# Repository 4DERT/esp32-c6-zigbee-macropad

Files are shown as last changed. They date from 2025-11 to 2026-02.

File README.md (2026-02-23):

# ESP32-C6 Zigbee Macropad

A compact, 3D-printable 6-key mechanical macropad powered by the ESP32-C6. This project functions as a stylish desk gadget that allows you to easily control your smart home devices via Zigbee. 

The custom 3D-printed enclosure features a dedicated mounting point specifically designed for the **DFRobot Beetle ESP32-C6** development board and supports standard mechanical keyboard switches (Cherry MX, Outemu, etc.).

<p align="center">
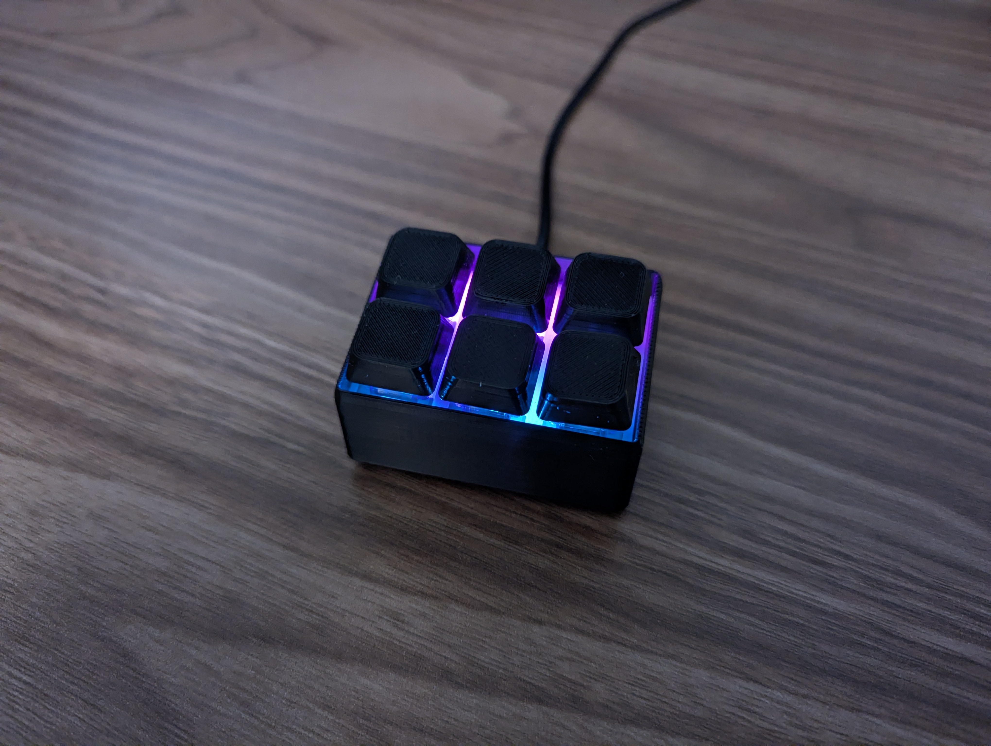
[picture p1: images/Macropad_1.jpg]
Macropad Main View
  
</p>

<p align="center">
  
</p>

## Features

* **6 Customizable Keys:** Supports up to 6 mechanical switches.
* **Multi-Action Support:** Every key independently supports **Single Press**, **Double Press**, and **Long Press** actions.
* **Zigbee Router Capability:** Can act as a Zigbee Router to extend your mesh network (configurable via `menuconfig` -> *Component config* -> *Zigbee* -> *Configure the Zigbee device type*).
* **RGB Lighting:** Support for WS2812 addressable LED strips with various animations. It also supports standard, non-addressable LEDs (like the board's built-in LED).
* **Function (FN) Layer:** A secondary layer is available for device management (accessed by holding a designated key, default is **Key 5**).
  * **Lighting Control:** Use the FN layer to change RGB effects, brightness, and colors.
  * **Configurable Activation:** You can set the FN layer to trigger via a standard *Classic Hold* (active while pressed) or via a *Long Press* (which frees up the single/double press actions of that key for additional Zigbee commands).
  * **Factory Reset:** Hold **FN (Key 5)** and press **Key 2** (the key directly above it) to factory reset the device and force it to leave the current Zigbee network.

## Gallery

<p align="center">
  <table>
    <tr>
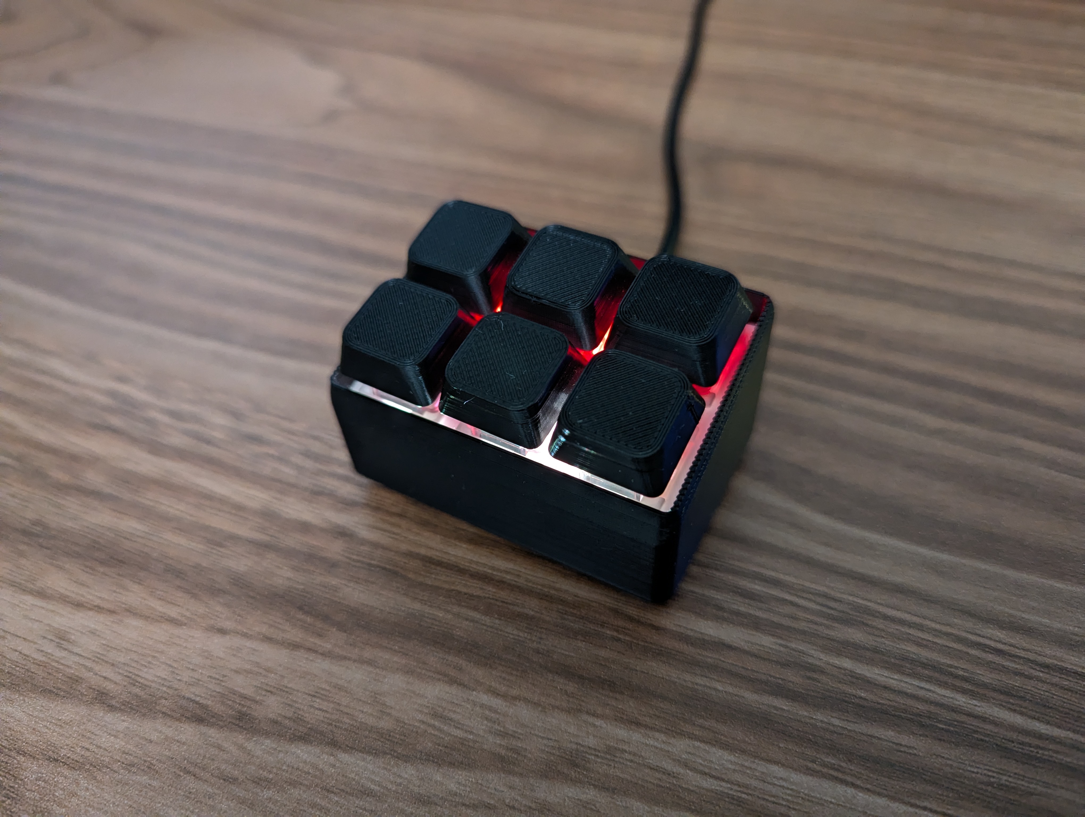
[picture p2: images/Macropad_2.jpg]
Macropad View 2
      <td></td>
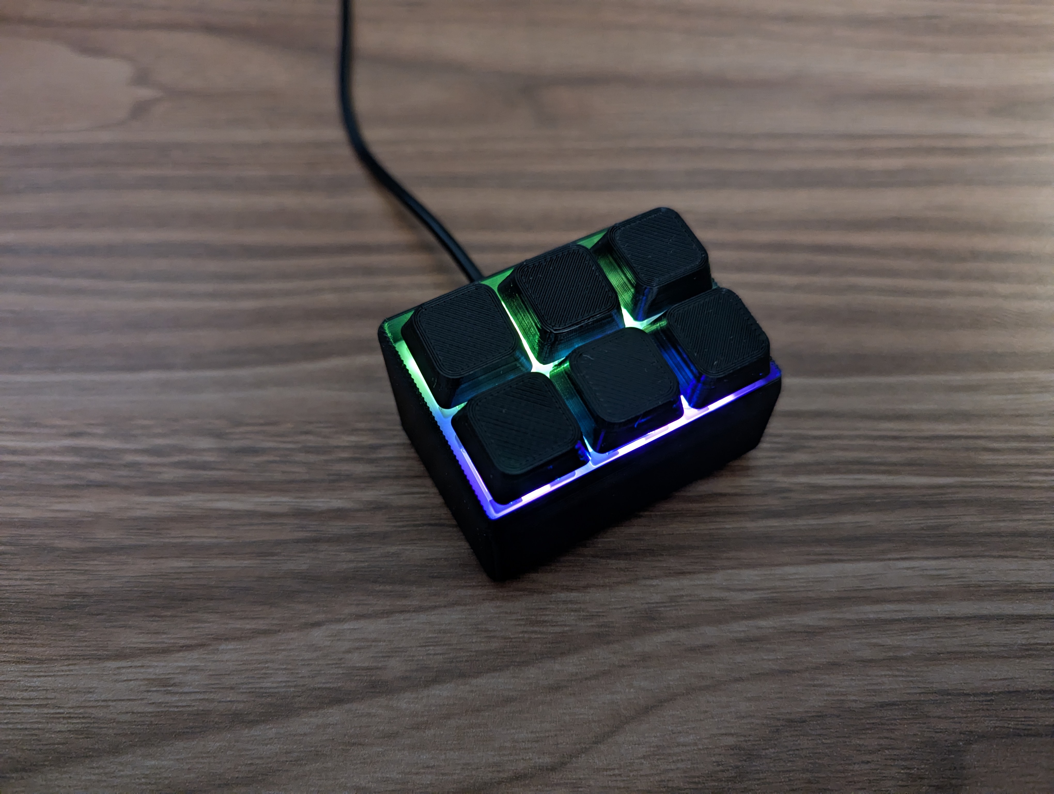
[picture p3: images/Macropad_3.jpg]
Macropad View 3
      <td></td>
    </tr>
    <tr>
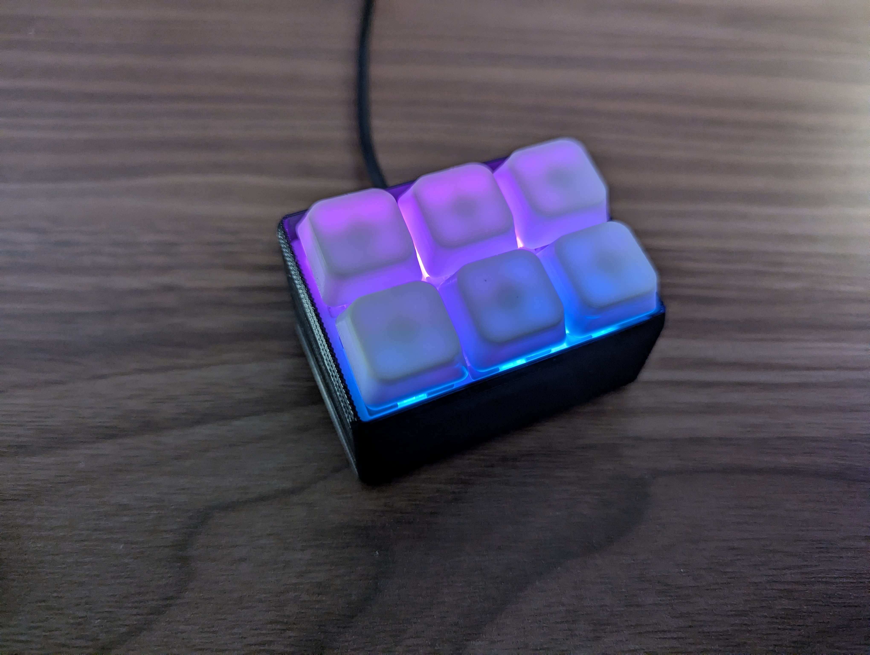
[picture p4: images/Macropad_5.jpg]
Macropad View 5
      <td></td>
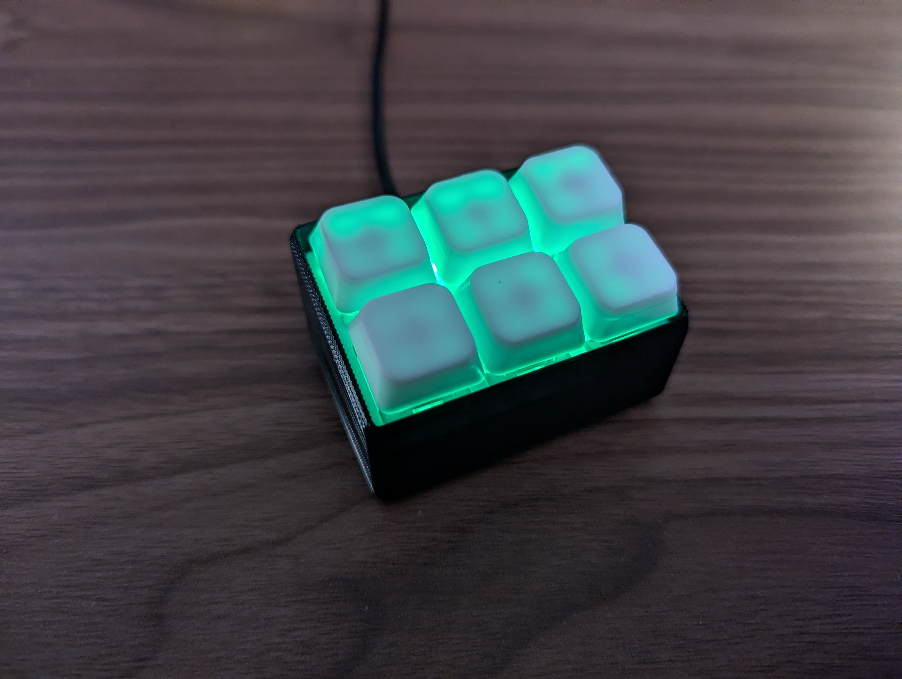
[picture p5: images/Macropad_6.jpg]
Macropad View 6
      <td></td>
    </tr>
  </table>
</p>

## 🛠️ Hardware & Components
* 1x [DFRobot Beetle ESP32-C6](https://www.dfrobot.com/product-2778.html)
* 6x Mechanical Keyboard Switches - pick your favorite color/feel - [Example Link](https://aliexpress.com/item/1005005876614581.html)
* *(Optional)* RGB Strip: 5mm WS2812B 100 LEDs/m. You only need 10 LEDs total (5 for each side) - [Example Link](https://aliexpress.com/item/1005006739134777.html)
* *(Optional)* 1x 100–470 µF Low ESR Capacitor (Highly recommended if using the WS2812 RGB strip)
* Hookup wire (silicone wire recommended for flexibility)
* 2x M2 20mm screws
* 1x M2 4mm screw (or 5mm with a washer)
* 3x M2 Knurled threaded inserts (M2\*3\*3.5)

## 3D Printing & Assembly
The `STL` folder contains all the core enclosure files (`Base`, `Plate`, etc.).

> **Note about Keycaps:** Keycap files are not included in the repository. You can use any standard keycaps that fit your chosen mechanical switches (e.g., Cherry MX compatible), or you can easily 3D print your own! If you want to print them, here is a great [DSA-like MX Keycap model on MakerWorld](https://makerworld.com/en/models/1412642-keycap-mx-dsa-like) that fits perfectly.

> **Printing Tip:** If you are using the addressable RGB strip, it is highly recommended to print the `Base` in **Black** (to prevent light bleed) and the `Plate` in **White** (to nicely diffuse the LED light).

1. Insert the knurled threaded nuts into the designated mounting posts in the base using a soldering iron.
2. Snap your mechanical switches into the printed `Plate`.
3. Solder wires to the switch pins and route them to the ESP32-C6. 

### Wiring Guide

| Button | ESP32-C6 GPIO |
| :---: | :---: |
| **0** | `GPIO 21` |
| **1** | `GPIO 22` |
| **2** | `GPIO 20` |
| **3** | `GPIO 7` |
| **4** | `GPIO 19` |
| **5** | `GPIO 6` |

Wiring Diagram

**RGB Strip (WS2812):** 
* Connect the data line to **GPIO 17**.
* Connect Power to **VIN** (5V) and Ground to **GND**. 
* *Note: It is highly recommended to solder a 100–470 µF Low ESR capacitor across VIN and GND to stabilize power for the LEDs.*

*(You can easily change the pinout configuration in `menuconfig`. The configuration above matches the pre-compiled binary available in the Releases tab).*

Once wired, carefully tuck the wiring and components into the enclosure and screw everything together.

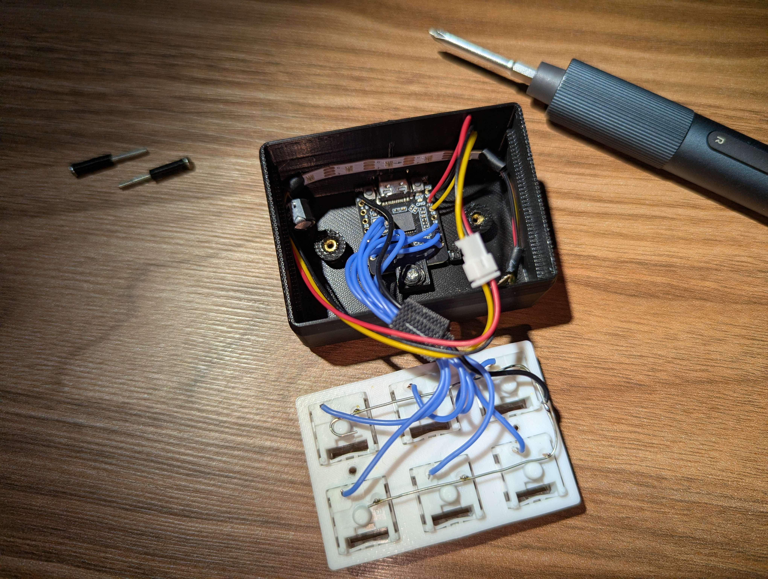
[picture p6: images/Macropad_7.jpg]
Internal Assembly


## Building & Flashing

### Quick Flash (Pre-compiled Binary)
If you don't want to set up a development environment, you can flash the pre-compiled firmware directly from your browser!

1. Download the latest firmware image (`.bin` file) from the `Releases page` of this repository.
2. Open the [ESP Web Flasher by Spacehuhn](https://esptool.spacehuhn.com/) in a Web Serial-compatible browser (e.g., Google Chrome or Microsoft Edge).
3. Connect your ESP32-C6 to your computer via USB and click **Connect** on the webpage.
4. Select the correct serial port for your device.
5. Upload the downloaded `.bin` file, set the flash address to `0x0`, and click **Program** to flash the device.

### Build from source code
1. Clone the repository and open it in **VS Code**.  
   A ready-to-use [Dev Container](https://code.visualstudio.com/docs/devcontainers/containers) configuration is provided. Once you open the project in VS Code with the *Dev Containers* extension installed, it will automatically pull an environment with **ESP-IDF**, Python tools, and all necessary dependencies preinstalled.  

2. If you prefer building locally (without Docker), install [ESP-IDF](https://docs.espressif.com/projects/esp-idf/en/latest/esp32c6/get-started/) on your machine.  

3. Configure your build options using `menuconfig`. Here you can customize GPIO pins, change the `MANUFACTURER_NAME`, `MODEL_IDENTIFIER`, and more.
    ```bash
    idf.py menuconfig
    ```

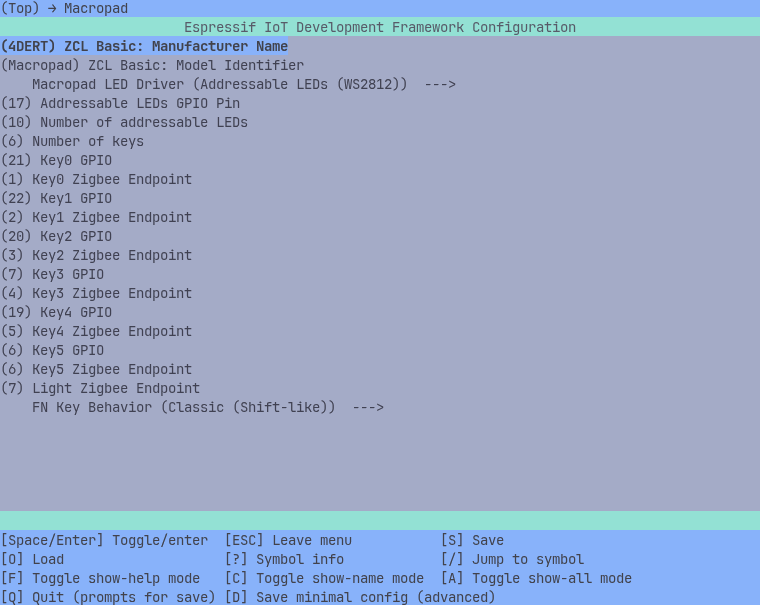
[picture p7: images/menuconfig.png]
ESP-IDF Menuconfig Interface


4. Set the target to ESP32-C6:
    ```bash
    idf.py set-target esp32c6
    ```

5. Build the project, flash it to your board, and open the serial monitor:
    ```bash
    idf.py build flash monitor
    ```

## First Boot & Zigbee Pairing

After flashing the firmware:

1. Power the device via USB.
2. The device will automatically enter Zigbee pairing mode.
3. In Home Assistant (ZHA), enable pairing and wait for the device to appear.

## Home Assistant Integration (ZHA)
To make integrating the macropad with Home Assistant as easy as possible, a pre-made automation template is included in this repository.

Instead of creating triggers from scratch, you can use the provided template and simply swap out the placeholder device address with your own.

**1. Find your Device IEEE Address:**
Every Zigbee device has a unique MAC address. To make the automation work, you need to find yours:
* In Home Assistant, navigate to **Settings** -> **Devices & Services**.
* Open **Zigbee Home Automation** integration.
* Find and select your Macropad from the device list.
* Under the **Device info** panel copy the `IEEE` address (it will look something like `7c:2c:67:ff:fe:51:a0:00`).

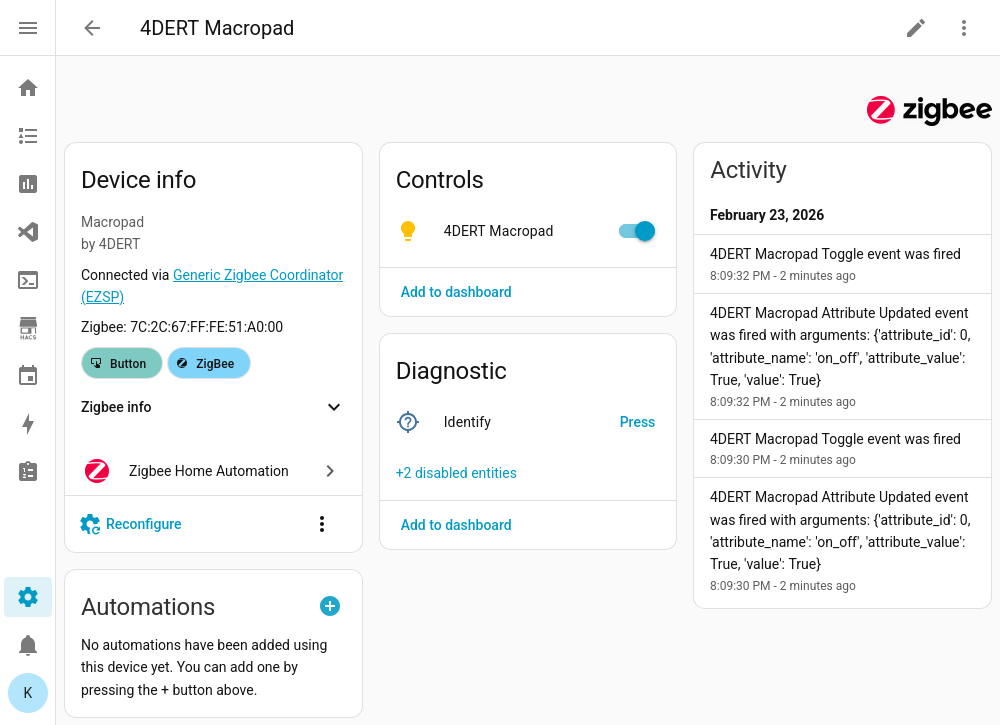
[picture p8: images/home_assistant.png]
Home Assistant Device Info


**2. Import the Automation:**
* Open the [`ha_automation_template.yaml`](ha_automation_template.yaml) file located in this repository and copy its contents.
* In Home Assistant, go to **Settings** -> **Automations & Scenes** and create a new automation.
* Click the three dots in the top right corner and select **Edit in YAML**.
* Paste the copied code.
* Use the search and replace function to replace the placeholder `7c:2c:67:ff:fe:51:a0:00` with the **Device IEEE** you copied in step 1.
* Save the automation, switch back to the Visual Editor, and assign your desired actions to each button press!

## Contributing

Contributions, issues, and feature requests are highly welcome! 

If you find a bug or have an idea for a new feature, please feel free to open an issue on the Issues page. 

If you want to contribute directly to the code or documentation, simply fork the repository, make your changes, and submit a **Pull Request**. 

## License

This project is open-source and available under the [MIT License](LICENSE).`

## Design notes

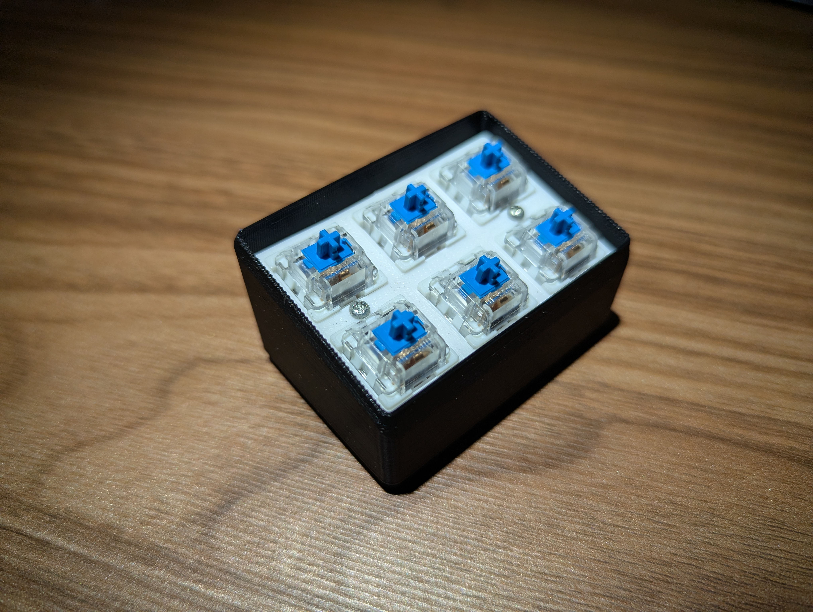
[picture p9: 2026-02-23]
images/Macropad_4.jpg

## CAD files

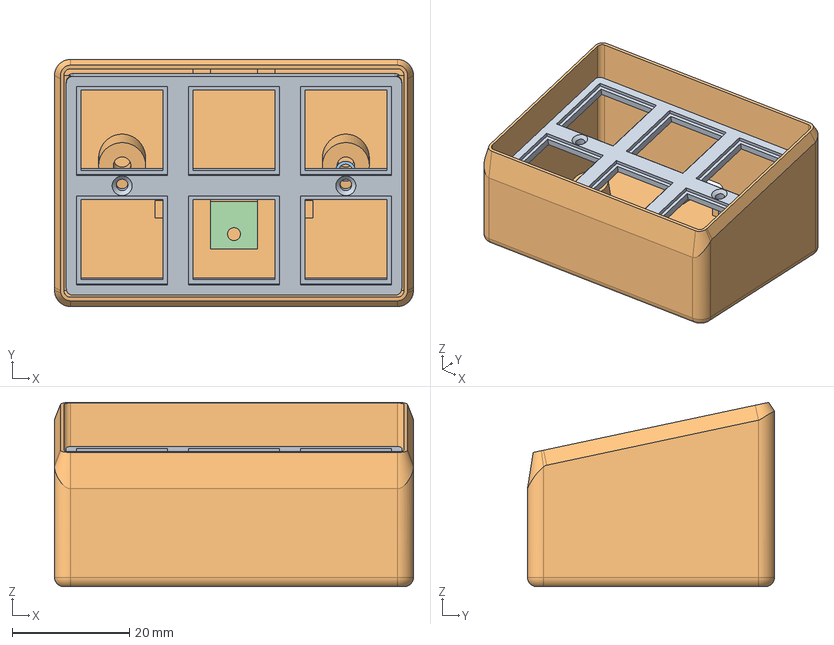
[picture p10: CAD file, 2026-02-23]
STL/MacroPad3x2.FCStd
61.1 x 42.1 x 31.4 mm
Plate
Base
Screw cover
ESP Lock

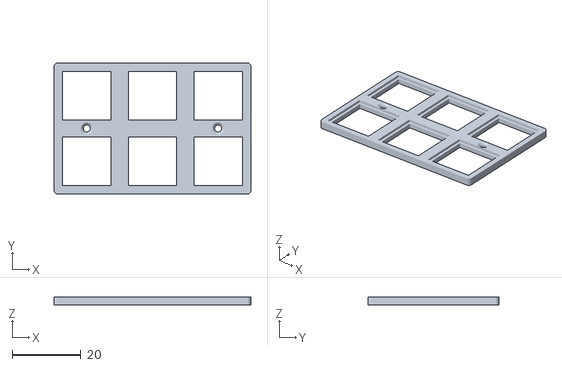
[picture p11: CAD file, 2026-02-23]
STL/Plate.stl
57.1 x 38.1 x 2.30

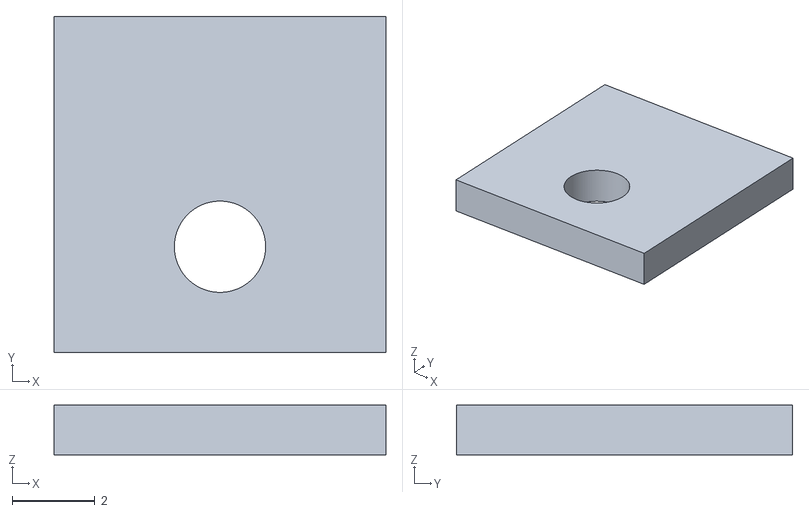
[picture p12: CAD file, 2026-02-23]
STL/ESP_lock.stl
8.00 x 8.10 x 1.20

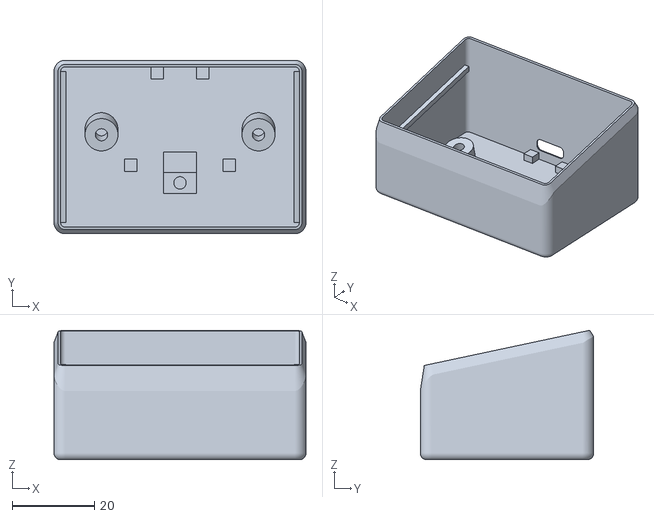
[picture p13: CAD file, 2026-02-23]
STL/Base.stl
61.1 x 42.1 x 31.4

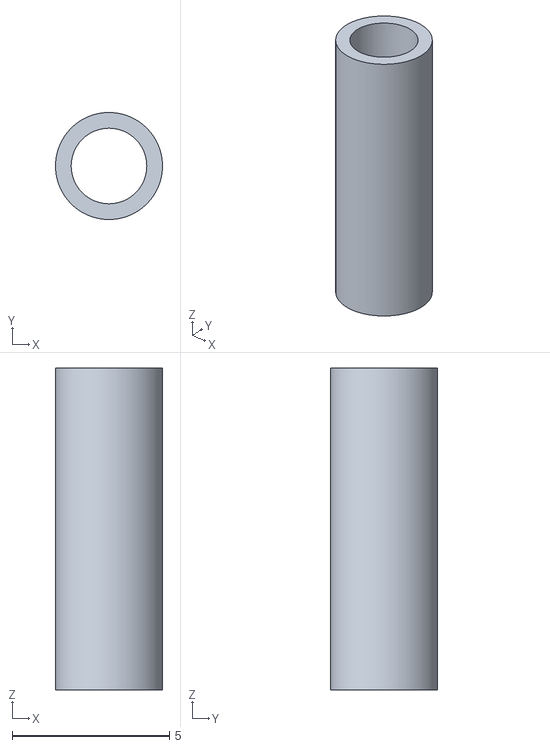
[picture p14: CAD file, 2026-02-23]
STL/Screw_cover.stl
3.40 x 3.40 x 10.2

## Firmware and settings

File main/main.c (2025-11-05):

#include <stdbool.h>
#include <stdlib.h>
#include <string.h>

#include "esp_check.h"
#include "freertos/FreeRTOS.h"
#include "nvs_flash.h"

#include "macropad.h"

static void init_nvs(void);

void app_main(void) {
    init_nvs();
    macropad_init();
}

/**
 * @brief Initialize non-volatile storage (NVS)
 */
static void init_nvs(void) {
    esp_err_t ret = nvs_flash_init();
    if (ret == ESP_ERR_NVS_NO_FREE_PAGES || ret == ESP_ERR_NVS_NEW_VERSION_FOUND) {
        ESP_ERROR_CHECK(nvs_flash_erase());
        ret = nvs_flash_init();
    }
    ESP_ERROR_CHECK(ret);
}

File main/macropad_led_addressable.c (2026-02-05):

#include "macropad_led.h"

#include "esp_log.h"
#include "freertos/FreeRTOS.h"

#include "lsfx.h"
#include "lsfx_fx_bicolor.h"
#include "lsfx_fx_loading.h"
#include "lsfx_fx_police.h"
#include "lsfx_fx_rainbow.h"
#include "lsfx_fx_static.h"

#define MACROPAD_LED_GPIO CONFIG_MACROPAD_ADDRESSABLE_LED_GPIO
#define MACROPAD_LED_NUM CONFIG_MACROPAD_LED_NUM

static const char* TAG = "LED_CTRL";

// 2D DATA STRUCTURE (EFFECTS -> VARIANTS)
typedef struct {
    const lsfx_fx_t* fx_func; // Pointer to the effect function (e.g., &lsfx_fx_rainbow_t)
    const void* fx_params;    // Pointer to the parameters (e.g., &g_rainbow_10s)
    const char* variant_name; // Name for logging
} effect_variant_t;

typedef struct {
    const char* effect_name;          // Name for logging (e.g., "Rainbow")
    const effect_variant_t* variants; // Pointer to the array of variants
    uint8_t num_variants;             // Size of the variants array
} app_effect_t;

// --- List of Variants for STATIC Effect ---
static const effect_variant_t static_variants[] = {
    {&lsfx_fx_static_t, &(const lsfx_fx_static_params_t){.red = 255, .green = 0, .blue = 0}, "Red"},
    {&lsfx_fx_static_t, &(const lsfx_fx_static_params_t){.red = 0, .green = 255, .blue = 0}, "Green"},
    {&lsfx_fx_static_t, &(const lsfx_fx_static_params_t){.red = 0, .green = 0, .blue = 255}, "Blue"},
    {&lsfx_fx_static_t, &(const lsfx_fx_static_params_t){.red = 255, .green = 255, .blue = 255}, "White"},
    {&lsfx_fx_static_t, &(const lsfx_fx_static_params_t){.red = 255, .green = 255, .blue = 0}, "Yellow"},
    {&lsfx_fx_static_t, &(const lsfx_fx_static_params_t){.red = 255, .green = 128, .blue = 0}, "Orange"},
    {&lsfx_fx_static_t, &(const lsfx_fx_static_params_t){.red = 128, .green = 0, .blue = 255}, "Purple"},
    {&lsfx_fx_static_t, &(const lsfx_fx_static_params_t){.red = 0, .green = 255, .blue = 255}, "Cyan"},
    {&lsfx_fx_static_t, &(const lsfx_fx_static_params_t){.red = 255, .green = 0, .blue = 255}, "Magenta"},
    {&lsfx_fx_static_t, &(const lsfx_fx_static_params_t){.red = 255, .green = 64, .blue = 128}, "Pink"},
    {&lsfx_fx_static_t, &(const lsfx_fx_static_params_t){.red = 64, .green = 255, .blue = 128}, "Mint"},
    {&lsfx_fx_static_t, &(const lsfx_fx_static_params_t){.red = 0, .green = 128, .blue = 255}, "Sky Blue"},
};
#define STATIC_VARIANTS_SIZE (sizeof(static_variants) / sizeof(static_variants[0]))

// --- List of Variants for RAINBOW Effect ---
static const effect_variant_t rainbow_variants[] = {
    {&lsfx_fx_rainbow_t, &(const lsfx_fx_rainbow_params_t){.period_ms = 45000}, "45s Period"},
    {&lsfx_fx_rainbow_t, &(const lsfx_fx_rainbow_params_t){.period_ms = 25000}, "25s Period"},
    {&lsfx_fx_rainbow_t, &(const lsfx_fx_rainbow_params_t){.period_ms = 2000}, "2s Period"},
};
#define RAINBOW_VARIANTS_SIZE (sizeof(rainbow_variants) / sizeof(rainbow_variants[0]))

// --- List of Variants for POLICE Effect ---
static const effect_variant_t police_variants[] = {
    {&lsfx_fx_police_t, &(const lsfx_fx_police_params_t){.period_ms = 400}, "400ms Period"},
    {&lsfx_fx_police_t, &(const lsfx_fx_police_params_t){.period_ms = 200}, "200ms Period"},
    {&lsfx_fx_police_t, &(const lsfx_fx_police_params_t){.period_ms = 100}, "100ms Period"},
};
#define POLICE_VARIANTS_SIZE (sizeof(police_variants) / sizeof(police_variants[0]))

// --- List of Variants for BICOLOR Effect ---
// clang-format off
static const effect_variant_t bicolor_variants[] = {
    // 1. Warm sunset gradient (red → orange)
    { &lsfx_fx_bicolor_t, &(const lsfx_fx_bicolor_params_t){
        .r1 = 255, .g1 = 64,  .b1 = 0,      // top: deep orange-red
        .r2 = 255, .g2 = 180, .b2 = 64 },   // bottom: warm amber
      "sunset glow" },

    // 2. Ocean tones (turquoise → deep blue)
    { &lsfx_fx_bicolor_t, &(const lsfx_fx_bicolor_params_t){
        .r1 = 0,   .g1 = 255, .b1 = 180,    // top: aqua turquoise
        .r2 = 0,   .g2 = 64,  .b2 = 255 },  // bottom: deep ocean blue
      "ocean" },

    // 3. Aurora colors (green → purple)
    { &lsfx_fx_bicolor_t, &(const lsfx_fx_bicolor_params_t){
        .r1 = 0,   .g1 = 255, .b1 = 128,    // top: vivid green-blue
        .r2 = 128, .g2 = 0,   .b2 = 255 },  // bottom: magenta-purple
      "aurora" },

    // 4. Cyberpunk neon (pink → blue)
    { &lsfx_fx_bicolor_t, &(const lsfx_fx_bicolor_params_t){
        .r1 = 255, .g1 = 0,   .b1 = 128,    // top: magenta-pink
        .r2 = 0,   .g2 = 128, .b2 = 255 },  // bottom: neon blue
      "synthwave" },

    // 5. Ice & fire contrast (blue → orange)
    { &lsfx_fx_bicolor_t, &(const lsfx_fx_bicolor_params_t){
        .r1 = 0,   .g1 = 64,  .b1 = 255,    // top: cold blue
        .r2 = 255, .g2 = 128, .b2 = 0 },    // bottom: warm orange
      "ice & fire" },

    // 6. Forest shades (dark green → light green)
    { &lsfx_fx_bicolor_t, &(const lsfx_fx_bicolor_params_t){
        .r1 = 0,   .g1 = 80,  .b1 = 0,      // top: deep green
        .r2 = 64,  .g2 = 255, .b2 = 64 },   // bottom: bright green
      "forest" },

    // 7. Classic red-blue look
    { &lsfx_fx_bicolor_t, &(const lsfx_fx_bicolor_params_t){
        .r1 = 255, .g1 = 0,   .b1 = 0,      // top: red
        .r2 = 0,   .g2 = 0,   .b2 = 255 },  // bottom: blue
      "red-blue" },

    // 8. Mystic Grape (purple → turquoise)
    { &lsfx_fx_bicolor_t, &(const lsfx_fx_bicolor_params_t){
        .r1 = 110, .g1 = 0,   .b1 = 160,    // top: grape purple
        .r2 = 0,   .g2 = 200, .b2 = 200 },  // bottom: turquoise
      "mystic grape" },

    // 9. Lava Pulse (deep red → gold)
    { &lsfx_fx_bicolor_t, &(const lsfx_fx_bicolor_params_t){
        .r1 = 180, .g1 = 0,   .b1 = 0,      // top: deep red
        .r2 = 255, .g2 = 180, .b2 = 40 },   // bottom: warm gold
      "lava pulse" },

    // 10. Arctic Mist (icy white → teal)
    { &lsfx_fx_bicolor_t, &(const lsfx_fx_bicolor_params_t){
        .r1 = 230, .g1 = 255, .b1 = 255,    // top: icy white
        .r2 = 0,   .g2 = 150, .b2 = 180 },  // bottom: dark cyan/teal
      "arctic mist" },

    // 11. Limeberry (lime → neon purple)
    { &lsfx_fx_bicolor_t, &(const lsfx_fx_bicolor_params_t){
        .r1 = 150, .g1 = 255, .b1 = 0,      // top: electric lime
        .r2 = 200, .g2 = 0,   .b2 = 255 },  // bottom: neon purple
      "limeberry" },
};
// clang-format on
#define BICOLOR_VARIANTS_SIZE (sizeof(bicolor_variants) / sizeof(bicolor_variants[0]))

// --- THE MASTER EFFECT LIST  ---
static const app_effect_t app_effects[] = {
    {"Rainbow", rainbow_variants, RAINBOW_VARIANTS_SIZE},
    {"Static", static_variants, STATIC_VARIANTS_SIZE},
    {"BiColor", bicolor_variants, BICOLOR_VARIANTS_SIZE},
    {"Police", police_variants, POLICE_VARIANTS_SIZE},
};
#define NUM_EFFECTS (sizeof(app_effects) / sizeof(app_effects[0]))

// -- Brightness --
static const uint8_t brightness_levels[] = {9, 21, 49, 84, 135, 199, 255};
#define BRIGHTNESS_LEVELS_NUM (sizeof(brightness_levels) / sizeof(brightness_levels[0]))
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

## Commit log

2025-10-09 Add keys component using espressif/button library
    Implements single, double and long press handling for up to 32 GPIO buttons.
    Integrated with main application and added button dependency to idf_component.yml.
2025-10-09 Refactor keys component: enhance documentation, improve initialization checks, and fix GPIO type in main
    [keys.c, main.c]
2025-10-10 Add reusable Zigbee Core component with endpoint registration API
    - Introduced new component `zigbee_core` (zb_core.c/.h) for Zigbee initialization and endpoint management.
    - Implemented attribute handler dispatching to per-endpoint user callbacks.
    - Added event-based connection tracking and factory reset handling.
    - Updated `main` to integrate Zigbee core with key input handling.
    - Created example endpoint with Basic, Identify, and On/Off clusters.
    - Added NVS initialization and improved project structure.
    [main.c]
2025-10-10 Add range extender endpoint configuration and update Zigbee stack initialization
    [partitions.csv]
2025-10-13 Move Zigbee initialization and connection handling into macropad module
    - Replaced `zbc_endpoint_attribute_handler` with `on_zbc_endpoint_attribute()` to handle attribute updates.
    - Added visual feedback on GPIO15 when receiving IDENTIFY cluster commands.
    - Moved Zigbee initialization (`zbc_init`, `zbc_start`, connection wait loop) from `main.c` into `macropad_init()`.
    - Added LED blinking on GPIO15 to indicate Zigbee network connection progress.
    - Simplified `main.c` to only initialize NVS and call `macropad_init()`.
    [macropad.c, main.c]
2025-10-13 Refactor LED control into dedicated module
    - Introduced new files `macropad_led.c` and `macropad_led.h` for encapsulated LED handling.
    - Defined LED GPIO, active level, and blink duration macros.
    - Added helper functions: `macropad_led_init()`, `macropad_led_on()`, `macropad_led_off()`, and `macropad_led_blink()`.
    - Updated `macropad.c` to use the new LED API instead of direct GPIO operations.
    - Simplified LED usage for key press events, Zigbee identify cluster feedback, and connection indication.
2025-10-13 Move Zigbee functionality to separate macropad_zigbee module
    - Created new files `macropad_zigbee.c` and `macropad_zigbee.h` to encapsulate all Zigbee logic.
    - Moved endpoint creation, command sending, and attribute handling from `macropad.c` to the new module.
    - Added `macropad_zb_init()`, `macropad_zb_start()`, `macropad_zb_is_connected()`, `macropad_zb_send()`, and `macropad_zb_create_endpoint()` APIs.
    - Integrated `macropad_led_blink()` feedback for IDENTIFY cluster actions.
    - Updated `macropad.c` to use the new Zigbee API instead of direct `zbc_*` calls.
    - Extended `.vscode/settings.json` with `"esp_check.h": "c"` for correct syntax highlighting.
    [macropad.c]
2025-10-13 Parameterize hardware & ZCL via Kconfig, factor Zigbee strings
    - Added `main/Kconfig.projbuild` with options for:
    - Status LED (GPIO, active level, blink period)
    - Key count and per-key GPIO/Zigbee endpoint mapping
    - ZCL Basic strings: Manufacturer Name & Model Identifier
    - Replaced hardcoded LED macros with `CONFIG_` values in `macropad_led.h`.
    - Reworked `macropad_map.h` to build key map from Kconfig (supports 1..6 keys).
    - `macropad_zigbee`:
    - Build ZCL char strings at runtime from Kconfig (with length prefix).
    - Added compile-time length checks; set BASIC attrs using prepared buffers.
    - `macropad.c`: now uses `macropad_zb_*` API exclusively.
    - Minor cleanup in `main.c` (removed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
    [main.c]
2025-10-24 Refactor key handling with FN layer support
    - Introduced dedicated FN mode state (`s_is_fn`) with clear enter/exit logic.
    - Added input validation for key IDs (`MACROPAD_KEY_COUNT` check).
    - Split logic into separate functions:
    - `handle_fn_key()` – toggles FN mode on long press/release.
    - `handle_fn_layer()` – handles FN+key combinations.
    - `handle_normal_layer()` – handles standard key events.
    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
2025-10-26 Add modular LED strip effects engine
    - Introduced new component `ledstrip_fx` providing a lightweight task-based
    LED strip rendering engine (lsfx) with thread-local pixel handling.
    - Implemented core API:
    - `lsfx_init()` — initialize LED strip and spawn render task.
    - `lsfx_set_fx()` — switch active visual effect asynchronously.
    - Added base effect interface `lsfx_fx_t` and callback-based frame generator.
    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
2025-10-27 Add static (solid color) effect and one-shot FX support
    - Added new effect `lsfx_fx_static_t` for solid color illumination.
    - Accepts `lsfx_fx_static_params_t { uint8_t red, green, blue }`.
    - Marks `is_one_time = true`, so it renders only once on activation.
    - Extended `lsfx_fx_t` with `is_one_time` flag to distinguish static vs. animated effects.
    - Updated `lsfx_task()` to handle one-time effects by pausing frame generation until a new FX arrives.
    - Added `LSFX_FRAME_TIME_MS` (default 20 ms) for configurable animation frame rate.
    - Fixed rainbow params naming (`lsfx_fx_rainbow_params_t`).
    - Updated `main.c` demo:
    - Shows switching between rainbow (animated) and static (one-shot) effec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
2025-10-27 Add brightness control
    - Core
    - Introduce frame rate macro `LSFX_FRAME_TIME_MS` (default 20 ms).
    - Add brightness state to `lsfx_t` with limits (`LSFX_BRIGHTNESS_MAX/MIN`).
    - Extend queue protocol with command wrapper `lsfx_cmd_t`
    (types: SET_FX, SET_BRIGHTNESS).
    - Public API: `lsfx_set_brightness()` to change global brightness at runtime.
2025-10-29 LSFX opaque handle; heap-backed init/deinit; null-guards
    - Hide internal state by moving struct to .c and introducing opaque type:
    - Replace `struct lsfx` exposure with `struct lsfx_t` private + `typedef struct lsfx_t* lsfx_handle_t`.
    - Change API:
    - `lsfx_init(...)` → returns `lsfx_handle_t` (allocates instance on heap).
    - Add `lsfx_deinit(lsfx_handle_t)` for cleanup (task/queue/strip/free).
    - Update all APIs to accept `lsfx_handle_t` (fx/brightness/enabled).
    - Renderer:
    - Update TLS pointer type to `lsfx_handle_t`.
    - Add NULL checks before queueing commands and in public setters.
    - Demo:
    - Adjust `main.c` to use the new handle-returning init and updated setters.
    [main.c]
2025-10-29 Add thread-safe getters and atomic state
    - API:
    - New getters: `lsfx_get_brightness()`, `lsfx_get_enabled()`, `lsfx_get_fx()`.
    - Introduce `lsfx_effect_binding_t { fx, params }` for returning active effect.
    - Concurrency:
    - Make `brightness`, `enabled`, and `active_fx` atomic.
    - Render loop snapshots state via `atomic_load` and updates via `atomic_store`.
    - Initialization:
    - Create/destroy `led_strip` in `lsfx_init()`/`lsfx_deinit()` (not in task).
    - Improve error handling and cleanup on init failures.
    - `main.c`: read back and log brightness/enabled/active FX using new getters.
    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
    [main.c]
2025-11-05 Fix: reload current state after applying command to prevent rendering with stale data
2025-11-05 Replace single GPIO LED with WS2812 addressable strip system
    - Implement LSFX-based LED control (effects, variants, brightness)
    - Add color presets and rainbow animation variants
    - Map FN keys to LED control functions (toggle, brightness, effect, variant)
    - Remove legacy macropad_led_on/off/blink functions
    - Integrate LED init into macropad startup (no more blink on connect -
    temporary)
    - Simplify main.c by removing old LED test code
    [macropad.c, main.c]
2025-11-05 Add parameterized Police effect with adjustable flash period
    - Extend lsfx_fx_police with configurable period_ms parameter
    - Update gen_frame() to read optional params instead of fixed 1s toggle
    - Add Police effect variants (100ms / 200ms / 400ms) to macropad LED list
    - Integrate Police effect into master effect table
2025-11-05 Add new BiColor LED effect with half-split gradient variants
    - Implement lsfx_fx_bicolor effect (static, one_time=true)
    - Add header and source files to component build
    - Each half of the LED strip displays a different color
    - Added 10 preset variants (sunset, ocean, aurora, synthwave, etc.)
    - Registered "BiColor" in macropad master effect list
2025-11-16 Move LED GPIO/NUM configuration to Kconfig and remove hardcoded defines
2025-11-16 Refactor LED driver system and fix missing lsfx.h include path
    - Added Kconfig choice `MACROPAD_LED_DRIVER` allowing selection between:
    - WS2812 addressable LED driver
    - Simple GPIO LED driver
    - Introduced new Kconfig options:
    - MACROPAD_ADDRESSABLE_LED_GPIO
    - MACROPAD_LED_NUM (only for WS2812 mode)
    - MACROPAD_LED_GPIO (only for GPIO mode)
    - Split LED logic into two dedicated source files:
    - macropad_led_addressable.c (WS2812 + LSFX effects)
    - macropad_led_gpio.c (simple single-LED mode)
    - Updated main CMakeLists:
    - Explicitly append driver-specific SRCS and REQUIRES
    - Added workaround for missing include propagation:
    `${CMAKE_SOURCE_DIR}/components/ledstrip_fx/inclu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
    [macropad_led_addressable.c, macropad_led_gpio.c]
2025-11-17 Add Zigbee On/Off Light endpoint for LED control
    This commit implements a dedicated Zigbee endpoint (Device ID 0x0100) to expose the Macropad's LED strip as a standard smart light.
    Key changes:
    * Zigbee Stack: Added macropad_zb_create_light_endpoint to register the On/Off Light device with necessary Server clusters (Basic, Identify, On/Off).
    * State Sync: Implemented bidirectional synchronization. Incoming Zigbee commands now control the physical LEDs, and manual toggles via the FN layer update the Zigbee ZCL attribute to notify the hub.
    * LED Driver: Added macropad_led_set_enabled and macropad_led_get_enabled APIs to both Addressable and GPIO drivers to allow absolute state setting.
    * Conf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
2025-11-17 Fix: sync initial LED state on Zigbee connection
    [macropad.c]
2025-11-17 Optimize default LED effects and brightness for better UX
    This commit refines the initial LED state and effect list to provide a more pleasing out-of-the-box experience, reducing the need for immediate manual adjustment.
    * Default Effect: Reordered the master effect list to start with 'Rainbow' instead of 'Static'.
    * Brightness: Reduced initial brightness from 100% to ~60% to prevent glare on startup.
    * Animation Speeds: Reordered Rainbow and Police variants to default to slower, smoother periods (e.g., 45s Rainbow, 400ms Police) rather than fast strobing.
    * BiColor Palette: Replaced generic color combinations with vibrant new presets (Mystic Grape, Lava Pulse, Arctic Mist, Lim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
    [macropad_led_addressable.c]
2025-11-17 Make FN key behavior configurable via Kconfig choice
    - Add MACROPAD_FN_MODE choice to Kconfig to select operation mode
    - Implement "Classic" mode: acts like Shift, immediate layer activation, no Zigbee commands
    - Implement "Dual" mode: hold for layer, short/double press sends Zigbee commands
    - Update key event handling logic to support both configurations via preprocessor directives
    - Map Kconfig selection to MACROPAD_FN_ON_LONG_PRESS define
    [macropad.c]
2026-02-05 Cleanup devcontainer and simplify LED logging
2026-02-05 Add Zigbee factory reset via Fn+Key2 long press
    [macropad.c]
2026-02-05 Add loading LED effect for startup and Zigbee Identify
    - New Effect: Implemented `lsfx_fx_loading` – a dedicated animation used to indicate a "joining to network" or "identifing" state.
    - Startup Sequence: The LED strip now displays the loading effect immediately upon initialization and persists until the Zigbee connection is fully established.
    - Zigbee Identify: Integrated the `Identify` cluster handling. The device now responds to hub identification requests (e.g., from Home Assistant) by triggering the loading animation.
    - Input Override: Added an `override_active` lock mechanism in the addressable LED driver. This prevents manual user inputs (brightness/effect cycling) fro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
    [macropad.c, macropad_led_addressable.c, macropad_led_gpio.c]
2026-02-05 Force Zigbee attribute report on local state change
    This resolves synchronization issues where toggling the LED via physical keys would not always reflect immediately in Home Assistant (ZHA).
2026-02-23 Add hardware assets, project documentation, and HA template
    - Add STL files and FreeCAD source for the 3D-printable enclosure
    - Upload project gallery images and demonstration GIF
    - Include Home Assistant automation template (ZHA)
    - Update README with assembly instructions and visuals
    [Base.stl, ESP_lock.stl, MacroPad3x2.FCStd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]
